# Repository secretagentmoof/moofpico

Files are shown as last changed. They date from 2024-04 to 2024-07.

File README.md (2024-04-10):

moofpico, a clone of a2pico 2.x (aka A2retronet RP2040)

This is a mostly-clone of the 2.4 through-hole [a2pico pcb board](https://github.com/rallepalaveev/a2pico), mostly for use as an Apple II <-> SD card interface, with a few minor tweaks. Why use this instead of one of the other boards out there? Mostly: no (E(E))PROMs, no PALs, nothing that needs to be programmed outside of using the Pico's USB connection - and designed so that almost all of the parts can be pretty easily hand-soldered.

The [RPi Pico datasheet](https://datasheets.raspberrypi.com/pico/pico-datasheet.pdf) explains some aspects that aren't made clear in either the schematic or its board symbol:
- the `3V3` pin is 3.3V in *and* out from the Pi unit; it's used to power both the RPi itself and can supply 300mA to other circuitry. Normally it's generated internally from...
- the `VSYS` pin is the main system input voltage (accepts 1.8V-5.5V); in our case, we can power it either from the apple II +5V slot, or from...
- the `VBUS` pin is connected to the uUSB pin1 connector; it can thus be used to power the unit when the Apple II itself is off, and...
- in section 4.5 they explicitly note how you should combine multiple power sources (VSYS + Schottky). TBH, I'm not sure why the DIP switch is needed.
- You can reset the RPi by pulling `RUN` low, or power the unit down entirely by pulling `3V3_EN` low.

While I don't think I'm allowed to redistribute the MEM2061 uSD socket footprint/3D model, you can grab it from DigiKey's model page: https://www.digikey.com/en/models/9859612 (the SnapMagic one). I've used the KiCad schematic symbol, even though it only has 11 pins and not 12 (extra is just shield ground).

The dimensions for apple2 peripheral cards is defined in IIgs tech note #28, https://mirrors.apple2.org.za/ftp.gno.org/doc/apple/technotes/iigs/tn.iigs.028

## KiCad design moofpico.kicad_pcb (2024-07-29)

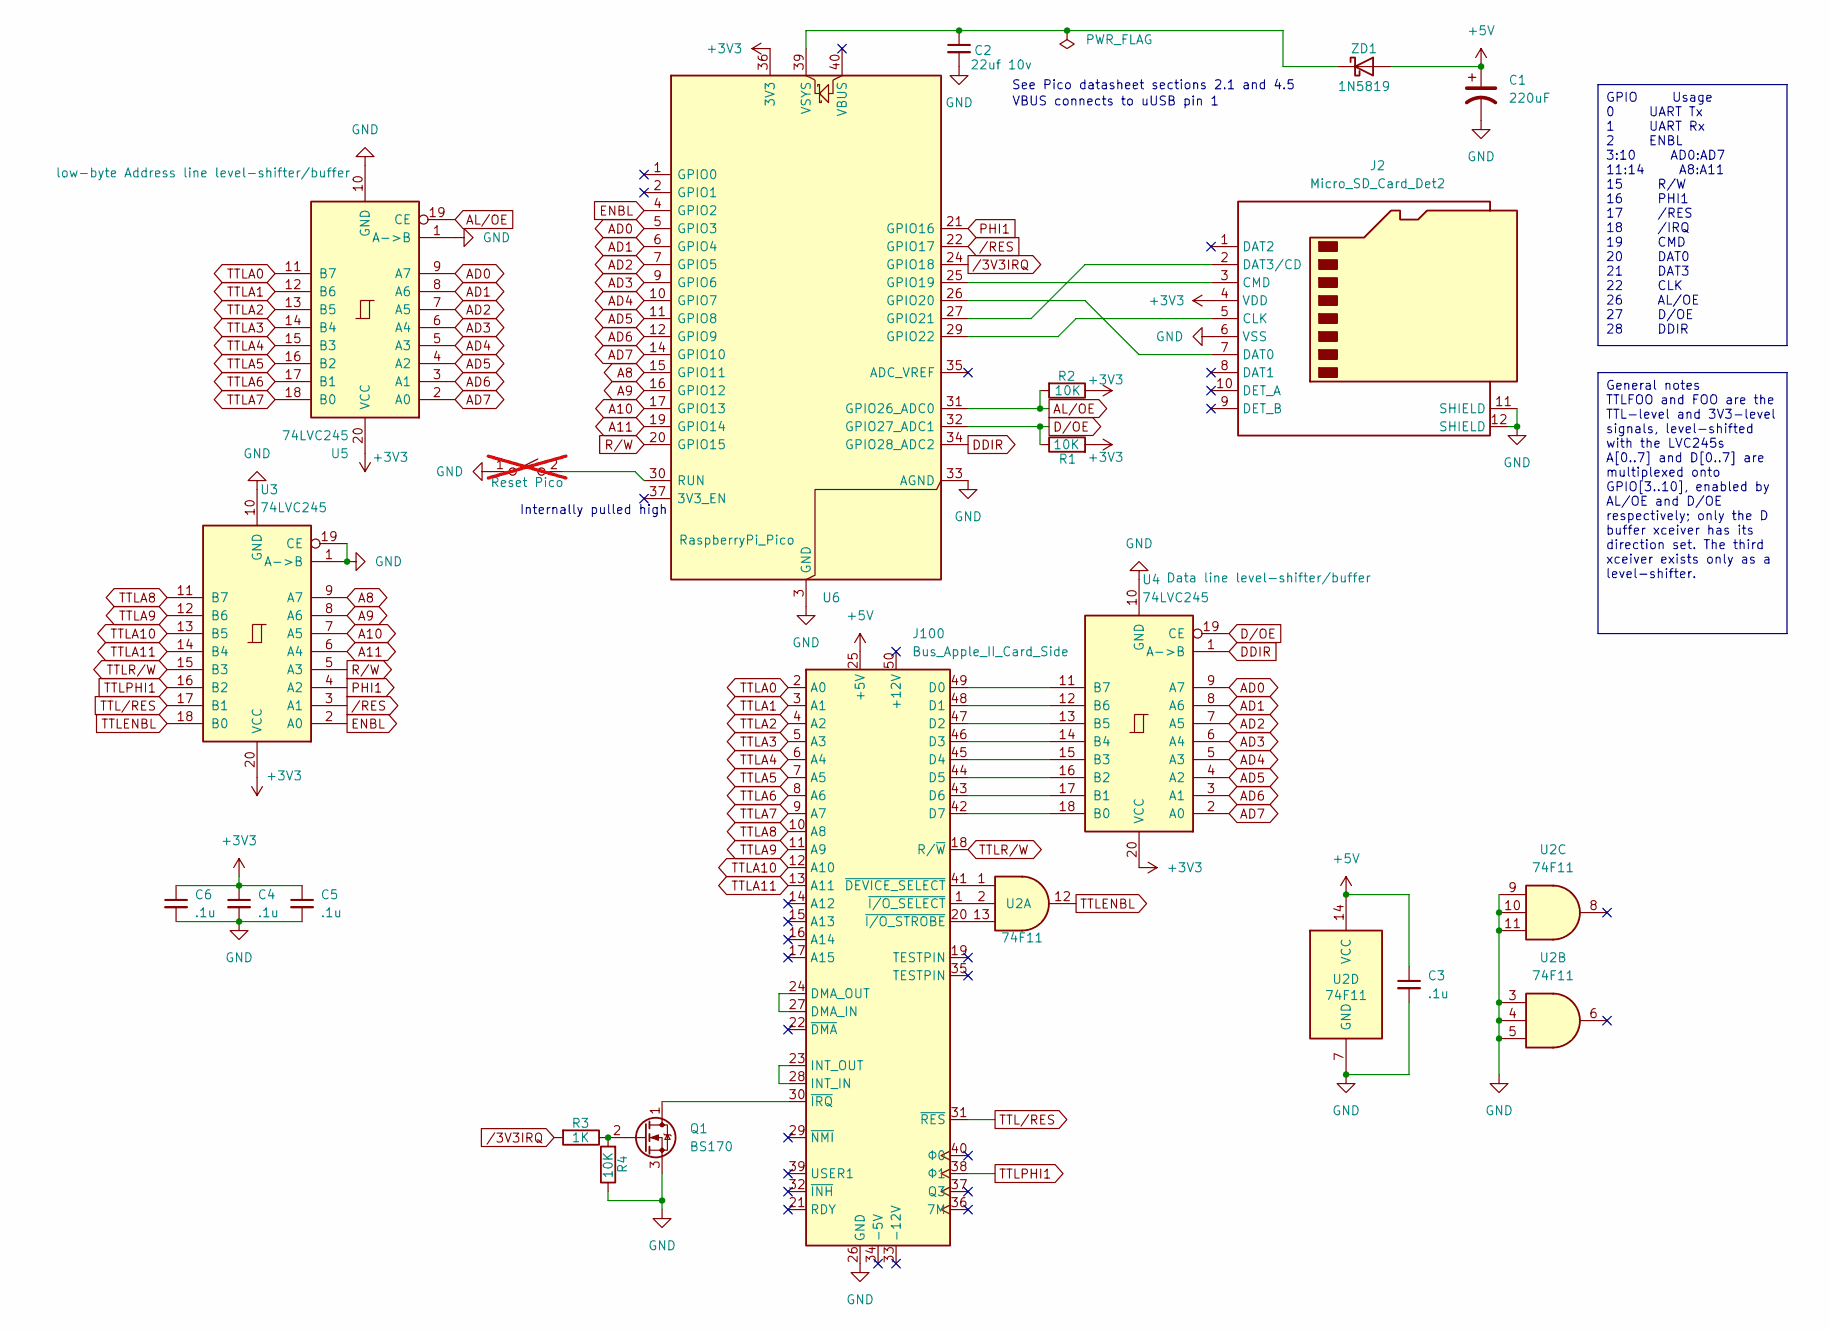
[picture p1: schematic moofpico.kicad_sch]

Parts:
C1: 220uF; CP_Radial_D6.3mm_P2.50mm
C2: 22uf 10v; C_Disc_D5.0mm_W2.5mm_P2.50mm
C3, C4, C5, C6: .1u; C_Disc_D3.8mm_W2.6mm_P2.50mm
J2: Micro_SD_Card_Det2; GCT_MEM2061-01-188-00-A_REVA
J100: Bus_Apple_II_Card_Side; Peripheral_Bus_Edge
Q1: BS170; TO-92_Inline
R1, R2, R4: 10K; R_Axial_DIN0207_L6.3mm_D2.5mm_P7.62mm_Horizontal
R3: 1K; R_Axial_DIN0207_L6.3mm_D2.5mm_P7.62mm_Horizontal
SW1: SW_SPST; PinSocket_1x02_P1.27mm_Vertical; not fitted
U2: 74F11; DIP-14_W7.62mm_Socket
U3, U4, U5: 74LVC245; DIP-20_W7.62mm_Socket
U6: RaspberryPi_Pico; RaspberryPi_Pico_Common
ZD1: 1N5819; D_DO-41_SOD81_P7.62mm_Horizontal

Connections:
+3V3: C4.1, C5.1, C6.1, J2.4 (VDD), R1.2, R2.1, U3.20 (VCC), U4.20 (VCC), U5.20 (VCC), U6.36 (3V3)
+5V: C1.1, C3.1, J100.25 (+5V), U2.14 (VCC), ZD1.2 (A)
A8: U3.9 (A7), U6.15 (GPIO11)
A9: U3.8 (A6), U6.16 (GPIO12)
A10: U3.7 (A5), U6.17 (GPIO13)
A11: U3.6 (A4), U6.19 (GPIO14)
AD0: U4.9 (A7), U5.9 (A7), U6.5 (GPIO3)
AD1: U4.8 (A6), U5.8 (A6), U6.6 (GPIO4)
AD2: U4.7 (A5), U5.7 (A5), U6.7 (GPIO5)
AD3: U4.6 (A4), U5.6 (A4), U6.9 (GPIO6)
AD4: U4.5 (A3), U5.5 (A3), U6.10 (GPIO7)
AD5: U4.4 (A2), U5.4 (A2), U6.11 (GPIO8)
AD6: U4.3 (A1), U5.3 (A1), U6.12 (GPIO9)
AD7: U4.2 (A0), U5.2 (A0), U6.14 (GPIO10)
AL/OE: R2.2, U5.19 (CE), U6.31 (GPIO26_ADC0)
DDIR: U4.1 (A->B), U6.34 (GPIO28_ADC2)
D/OE: R1.1, U4.19 (CE), U6.32 (GPIO27_ADC1)
ENBL: U3.2 (A0), U6.4 (GPIO2)
GND: C1.2, C2.2, C3.2, C4.2, C5.2, C6.2, J2.6 (VSS), J2.11 (SHIELD), J2.12 (SHIELD), J100.26 (GND), Q1.3 (S), R4.1, SW1.1 (A), U2.3, U2.4, U2.5, U2.7 (GND), U2.9, U2.10, U2.11, U3.1 (A->B), U3.10 (GND), U3.19 (CE), U4.10 (GND), U5.1 (A->B), U5.10 (GND), U6.3 (GND), U6.8 (GND), U6.13 (GND), U6.18 (GND), U6.23 (GND), U6.28 (GND), U6.33 (AGND), U6.38 (GND)
unnamed: J2.5 (CLK), U6.29 (GPIO22)
unnamed: J2.3 (CMD), U6.25 (GPIO19)
unnamed: J2.7 (DAT0), U6.26 (GPIO20)
unnamed: J2.2 (DAT3/CD), U6.27 (GPIO21)
unnamed: J100.49 (D0), U4.11 (B7)
unnamed: J100.48 (D1), U4.12 (B6)
unnamed: J100.47 (D2), U4.13 (B5)
unnamed: J100.46 (D3), U4.14 (B4)
unnamed: J100.45 (D4), U4.15 (B3)
unnamed: J100.44 (D5), U4.16 (B2)
unnamed: J100.43 (D6), U4.17 (B1)
unnamed: J100.42 (D7), U4.18 (B0)
unnamed: J100.24 (DMA_OUT), J100.27 (DMA_IN)
unnamed: J100.23 (INT_OUT), J100.28 (INT_IN)
unnamed: J100.41 (~DEVICE_SELECT), U2.1
unnamed: J100.30 (~IRQ), Q1.1 (D)
unnamed: J100.1 (~I/O_SELECT), U2.2
unnamed: J100.20 (~I/O_STROBE), U2.13
unnamed: Q1.2 (G), R3.1, R4.2
unnamed: SW1.2 (B), U6.30 (RUN)
unnamed: C2.1, U6.39 (VSYS), ZD1.1 (K)
PHI1: U3.4 (A2), U6.21 (GPIO16)
R/W: U3.5 (A3), U6.20 (GPIO15)
TTLA0: J100.2 (A0), U5.11 (B7)
TTLA1: J100.3 (A1), U5.12 (B6)
TTLA2: J100.4 (A2), U5.13 (B5)
TTLA3: J100.5 (A3), U5.14 (B4)
TTLA4: J100.6 (A4), U5.15 (B3)
TTLA5: J100.7 (A5), U5.16 (B2)
TTLA6: J100.8 (A6), U5.17 (B1)
TTLA7: J100.9 (A7), U5.18 (B0)
TTLA8: J100.10 (A8), U3.11 (B7)
TTLA9: J100.11 (A9), U3.12 (B6)
TTLA10: J100.12 (A10), U3.13 (B5)
TTLA11: J100.13 (A11), U3.14 (B4)
TTLENBL: U2.12, U3.18 (B0)
TTLPHI1: J100.38 (Φ1), U3.16 (B2)
TTLR/W: J100.18 (R/~W), U3.15 (B3)
TTL/RES: J100.31 (~RES), U3.17 (B1)
/3V3‏IRQ: R3.2, U6.24 (GPIO18)
/RES: U3.3 (A1), U6.22 (GPIO17)

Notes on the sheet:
General notes TTLFOO and FOO are the TTL-level and 3V3-level signals, level-shifted with the LVC245s A[0..7] and D[0..7] are multiplexed onto GPIO[3..10], enabled by AL/OE and D/OE respectively; only the D buffer xceiver has its direction set. The third xceiver exists only as a level-shifter.
GPIO Usage 0 UART Tx 1 UART Rx 2 ENBL 3:10 AD0:AD7 11:14 A8:A11 15 R/W 16 PHI1 17 /RES 18 /IRQ 19 CMD 20 DAT0 21 DAT3 22 CLK 26 AL/OE 27 D/OE 28 DDIR
See Pico datasheet sections 2.1 and 4.5
VBUS connects to uUSB pin 1
Internally pulled high

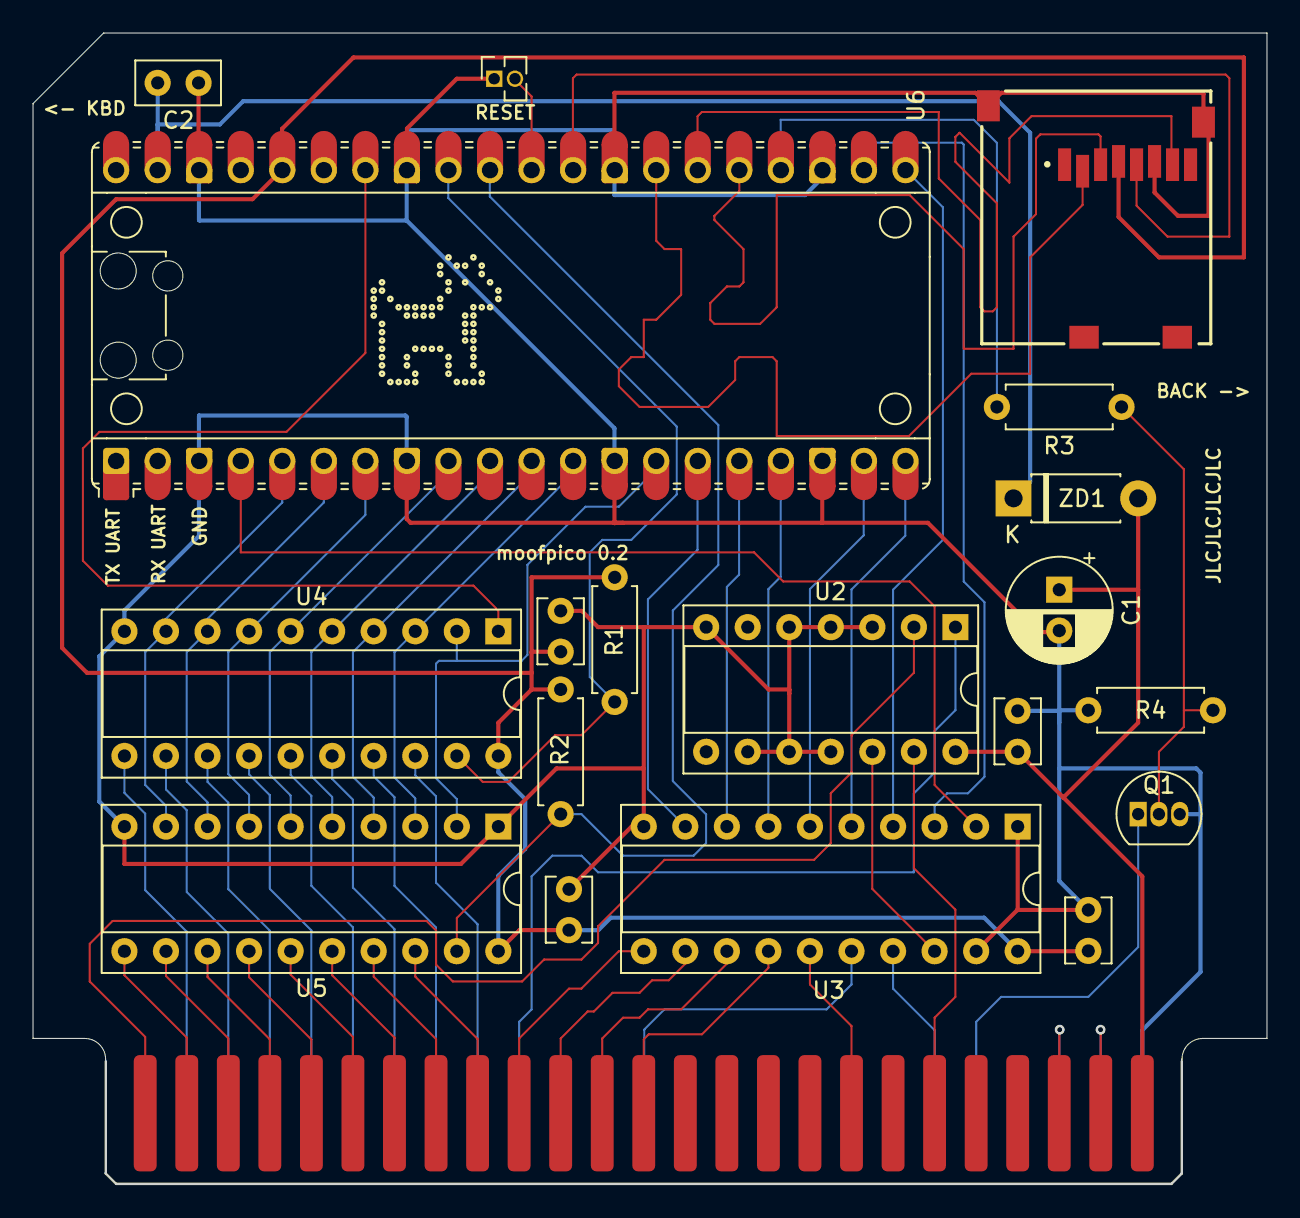
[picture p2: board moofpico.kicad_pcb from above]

Board: 2 copper layers, 75.4 x 70.4 mm, 20 parts (0 on the bottom side), 60 nets.

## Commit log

2024-03-08 moofpico, a clone of the 2.x through-hole a2pico
    [moofpico.kicad_pcb, moofpico.kicad_sch]
2024-03-14 fix submodules
    track libraries/footprints
    track libraries/footprints
2024-03-14 resync w/ libraries
    add fp/sym for MEM2061
    pretty sure I can't redistribute the MEM2061 footprints, alas
    [moofpico.kicad_pcb, moofpico.kicad_sch]
2024-03-14 use MEM2061 instead of "generic" SD
    [moofpico.kicad_pcb, moofpico.kicad_sch]
2024-03-14 make +3V3 and GND a little thicker; move +3V3 trace out from between some other RPi traces and onto its own test point/header pin/quasi-via
    faffing about with power and ground
    but *why*?
    [moofpico.kicad_pcb, moofpico.kicad_sch]
2024-03-14 update datasheet URLs; add extra shield pin to uSD
    more accurately specify capacitor size
    nudged rpi over so that it sat on the mill grid
    more footprint futzing
    move to 5 pin serial/power connector
    [moofpico.kicad_pcb, moofpico.kicad_sch]
2024-03-14 remove the interior two layers; should have never been there to begin with
    notey notey note
    [moofpico.kicad_pcb, moofpico.kicad_sch]
2024-03-14 checkpoint: moved the SD card around
    [moofpico.kicad_pcb, moofpico.kicad_sch]
2024-03-14 got rid of the vias
    don't sneak by that stupid square pin
    [moofpico.kicad_pcb]
2024-03-14 more minor trace tweaking
    [moofpico.kicad_pcb]
2024-03-14 use ki-lime-pi-pico footprint, since it has a bunch of extra stuff (keepouts and holes) - which required rerouting a whole bunch of stuff
    labels, whee
    [moofpico.kicad_pcb, moofpico.kicad_sch]
2024-03-14 fix paths for 3d model
    [moofpico.kicad_pcb]
2024-03-14 I do love how resynchronizing with the schematic changes all the UUIDs
    [moofpico.kicad_pcb]
2024-03-15 this side towards enemy
    [moofpico.kicad_pcb]
2024-03-17 more faffing about with moving components
    [moofpico.kicad_pcb, moofpico.kicad_sch]
2024-03-25 checkpoint: kicad 8.0.1, move components around
    [moofpico.kicad_pcb, moofpico.kicad_sch]
2024-03-26 move footprint so that the card edges are aligned with the (mil) grid
    [moofpico.kicad_pcb]
2024-03-26 probably voodoo at this point, but: add another decoupling cap (although I seriously doubt it's needed at this point) provide enough space on the board so q1, c1, and f1 can all be bent flat
    [moofpico.kicad_pcb, moofpico.kicad_sch]
2024-03-26 more movin'
    [moofpico.kicad_pcb]
2024-03-28 swap nand pin assignments around
    [moofpico.kicad_pcb, moofpico.kicad_sch]
2024-03-28 more probably needless shuffling around of components
    [moofpico.kicad_pcb]
2024-03-29 ground unused NAND inputs
    [moofpico.kicad_pcb, moofpico.kicad_sch]
2024-03-30 muck about with silkscreen; deem version 0.1
    [moofpico.kicad_pcb, moofpico.kicad_sch]
2024-04-10 move to 1x dip (even though it's more expensive than 2x?); swap enbl and phi1 to make the pcb layout ever so slightly nicer
    [moofpico.kicad_pcb, moofpico.kicad_sch]
2024-04-21 minor fiddling, NFCI
    [moofpico.kicad_pcb, moofpico.kicad_sch]
2024-04-24 more gratuitous track fiddling
    [moofpico.kicad_pcb]
2024-04-27 major design change: get rid of the uart headers and usb power dip switch I'm not convinced they're actually needed, and the stuff around the USB power in the pico manual makes me think it's superflu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
    [moofpico.kicad_pcb, moofpico.kicad_sch]
2024-05-01 add (unpopulated) reset button for pico; fix direction of IRQ (NFCI)
    [moofpico.kicad_pcb, moofpico.kicad_sch]
2024-05-24 equalize SD track lengths
    [moofpico.kicad_pcb]
2024-05-25 silly colinear tracks messed up the total length calculation, sigh
    [moofpico.kicad_pcb]
2024-06-18 honestly, don't remember - and kicad changes stuff arbitrarily anyway
    [moofpico.kicad_pcb]
2024-07-29 updated pi and apple II slots; NFCI
    [moofpico.kicad_pcb, moofpico.kicad_sch]
